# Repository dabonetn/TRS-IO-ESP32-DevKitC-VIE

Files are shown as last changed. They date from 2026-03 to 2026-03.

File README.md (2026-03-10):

# TRS-IO

WORK IN PROGRESS

DO NOT USE YET!

TRS-IO gives a TRS-80 Model 1/III online capabilities and provides
access to a variety of services. TRS-IO currently features the
following capabilities:

1. Access to the <a href="https://retrostore.org">RetroStore</a>
2. <a href="http://frehd.com">FreHD</a> emulation
3. Access to files mounted on a SMB share or located on a micro-SD card
4. Access to remote servers via TCP
5. Virtual printer support

The TRS-IO versions for the Model 1 and Model III have some additional features that
are explained below. The following sections give an overview of TRS-IO as well as setup
instructions. This Github repository contains the complete source code
as well as the KiCad schematics for the PCB (Printed Circuit Board).
For the following descriptions it is assumed that an assembled TRS-IO
card is available.

### Overview

The figure below depicts the overall architecture. The TRS-80 machine
is connected to TRS-IO via the I/O bus.  TRS-IO has a WiFi module that
connects to the local WiFi router. This allows TRS-IO to connect to
the Internet and access various services. Note that TRS-IO can only
connect to a 2.4 GHz WiFi network. It is recommended to use an IPEX
antenna to improve WiFi reception.



### Prerequisites

TRS-IO requires a TRS-80 Model III with 48kB of RAM or a Model 1 with 16kB of RAM.
Floppy disk drives or a cassette tape are not required.

### Power Supply

There are two versions of TRS-IO that are tailored to the Model 1 and Model III. Each version makes use of an ESP32 microcontroller
as well as a Tang Nano 9K FPGA. Both the ESP32 microcontroller as well as the Nano 9K need to be powered. There are two ways of doing
this.

* Power each module independently via two USB cables that connect to the ESP32's micro-USB and the Nano 9K's USB-C connector.
  For this option, the "VU" jumper (mentioned below), <b>SHOULD NOT BE USED</b>.
* Power the ESP32 via the Nano 9K or vice versa. For this option, only one of the modules need to be provided with power. This option
  requires the "VU" jumper.
  
In the following, each variant of TRS-IO is explained in detail.

### TRS-IO for the Model III

The following figure shows the top view of the TRS-IO card for the Model III:



1. 50-pin I/O bus connector
2. High resolution graphics connector
3. 3.5mm audio jack
4. VU jumper
5. HDMI connector
6. Micro-SD card reader
7. Multi-color status LED
8. Micro-USB and USB-C connector
9. Status button

The TRS-IO card needs to be connected to the TRS-80 Model III's I/O
bus via a 50-pin ribbon cable (1). Furthermore, the TRS-IO card needs
a separate power supply via a standard 5V USB charger. Please refer
to the previous section regarding the power supply. The status button
(9) and the multi-color status LED (7) will be explained in the
configuration section. The micro-SD card reader is underneath the
Nano 9K module (6). The 3.5mm audio jack (3) can be connected to a standard
speaker for game sound and Orchestra 90 support. If the high resolution
connectors (2) are connected to the TRS-80, the HDMI connector (5) will
generate a video signal.

### TRS-IO for the Model 1

The following figure shows the top view of the TRS-IO card for the Model 1:



1. 40-pin I/O bus connector
2. Micro-SD card reader
3. HDMI connector
4. Micro-USB and USB-C connector
5. Multi-color status LED
6. Status button
7. VU jumper

The TRS-IO version for the Model 1 features a 40-pin connector that can
directly be connected via a ribbon cable to the I/O bus of a Model 1.
This version of TRS-IO offers the following features:

* HDMI signal of the M1's video screen that includes game sound.
* Upper 32kB RAM (emulated by the Nano 9K FPGA) for a total of 48kB of total RAM.
* 25ms heartbeat timer to trigger the realtime clock.
* FreHD auto-boot for an unmodified M1.

The HDMI connector (3) can be used instead of a CRT monitor. TRS-IO for the M1
also emulates the LE18 graphics cards. The color of the HDMI signal can
be set to white (X=0), green (X=1), and amber (X=2) via the following OUT statements:

```OUT 31,0:OUT 31,5:OUT 31,X```

Please refer to an earlier section on how to provide power to TRS-IO.

### Configuring TRS-IO

The core of the TRS-IO card is an ESP32 microcontroller that features
a WiFi module that is used to connect to a WiFi router. After
physically connecting the TRS-IO card to a TRS-80 Model 1/III as
explained in the previous sections, the WiFi module on the ESP32
microcontroller first needs to be be configured with the credentials
of the local WiFi network.

While in setup mode, the TRS-IO's status LED will continuously blink
in white to indicate that it has not yet been configured. While in
that mode, TRS-IO will create an open access point called
"TRS-IO". Use a laptop to connect to this WiFi network and then use a
browser to visit URL <a
href="http://trs-io.local">trs-io.local</a>. The following web page
should appear in the browser:

<img src="doc/trs-io-web-ui.png" width="50%" />

Some hosts do not correctly handle mDNS that is used to resolve <a
href="http://trs-io.local">trs-io.local</a>. In that case, visit the
IP address <a href="http://192.168.4.1">192.168.4.1</a> instead.
The web interface shown above can be used to configure SSID and password of the WiFi
network that TRS-IO should connect to, the local timezone as well as
the credentials of a SMB share. For open networks leave the WiFi
password field empty. Note that TRS-IO cannot connect to WiFi networks
that use a capture portal. The timezone as well as the SMB share are
not required but will result in limited functionality.

Once all the information is provided, click on submit to upload the
parameters. TRS-IO will automatically reboot and try to connect to the
specified WiFi network. If successful, the LED will turn green for a
few seconds. If the credentials are wrong or if the specified WiFi
network is not accessible, the LED light will turn permanently red.

Note that TRS-IO will store all parameters in its local flash memory,
so the setup only needs to be performed once. Once TRS-IO is connected
to a WiFi router, it should still be possible to access URL <a
href="http://trs-io.local">trs-io.local</a> from a browser on the same
WiFi network. If mDNS is not supported by the host, the following BASIC
program can be used to determine TRS-IO's local IP address that was
assigned by the router:

```
10 OUT 236,16
20 OUT31,0:OUT31,4
30 C=INP(31):IF C=0 THEN END
40 PRINT CHR$(C);
50 GOTO 30
```

The web interface will also display two icons to indicate the status
of the SMB share and the micro-SD card (see screenshot above). Green
icons indicate that TRS-IO has access. Red icons indicate an error.
In that case, hovering the mouse over the red icon will display the
error message. It should be noted that TRS-IO needs to be rebooted
whenever a micro-SD card is inserted or ejected.

Pushing the status button will make the LED flash twice. The first time for
the WiFi status (green: WiFi connected; red: WiFi not connected) and a
second time for the SMB status (green: connected to SMB share; red:
not connected to SMB share). With proper configuration parameters, the
LED should flash green twice. Holding down the push button for more
than three seconds will erase all configuration parameters and place
TRS-IO back into setup mode (status LED flashing white). This
might be necessary if TRS-IO is moved to a different WiFi network.

The status LED indicates the state of TRS-IO:

* Blinking white: TRS-IO is not configured. It will create an open WiFi access point named "TRS-IO"
* Solid green: when TRS-IO has been configured with WiFi credentials and TRS-IO was able
  to connect to the WiFi network, the status LED will light in solid green for several seconds.
* Solid red: TRS-IO was configured with WiFi credentials but it was not possible to connect to the specified
  network. The reason could be wrong credentials or the specified network is itself offline. The push button can be
  used to reset TRS-IO into setup mode in case different credentials need to be provided.
* Solid blue: TRS-IO performs an OTA (Over-the-Air) update. TRS-IO will automatically detect
  newer firmware versions and will download and install the new firmware. The status LED will light solid blue during
  this process.
* Off: the status LED will be off during regular operations when TRS-IO is connected to the specified
  WiFi network and ready to accept commands from the TRS-80 Model III.
 
### FreHD

TRS-IO is compatible with the popular <a
href="http://frehd.com">FreHD</a> hard disk emulator. The FreHD disk
images can either be stored on a SMB share or on a micro-SD card.
If a micro-SD card is inserted, it will take precedence over
a mounted SMB share. Once TRS-IO is configured to access a SMB share,
simply copy the required files such as <a
href="http://members.iinet.net.au/~ianmav/trs80/downloads.htm">FREHD.ROM</a>
to the SMB share. Alternatively, the disk images can be transferred
to the micro-SD card. The IMPORT/EXPORT utilities will access files on the
SMB share or micro-SD card respectively.

### Virtual Printer Interface

TRS-IO support a virtual printer interface. Visiting <a
href="http://trs-io.local/printer">trs-io.local/printer</a> from a browser
will open the printer interface. Any printer output from the M1/MIII will
be displayed in the printer interface. If the host cannot resolve the mDNS name
trs-io.local, the above BASIC program can be used to determine the TRS-80's
IP address.

 ### Launching the native RetroStore Client

The <a href="https://retrostore.org">RetroStore</a> hosts applications
for the Tandy Radio Shack vintage computers and allows to seamlessly
download and run these applications without the need of cassettes or
floppy disks. TRS-IO acts as a gateway to the <a
href="https://retrostore.org">RetroStore</a>. This requires to run a
program on the TRS-80 that interfaces with TRS-IO. This program is
available as a regular <a
href="https://github.com/apuder/TRS-IO/raw/master/src/esp/components/retrostore/rsclient.cmd">CMD</a>
executable.  For TRS-80 machines with attached physical floppy disks,
this CMD executable can be copied to a floppy disk and launched the
usual way. For TRS-80 machines that have neither floppy disk drives
nor cassette drives, it is also possible to bootstrap the native
client via the following short BASIC program:
 
 ```BASIC
 10 OUT236,16
 20 OUT31,3
 30 OUT31,1
 40 N=INP(31)+256*INP(31)
 50 FOR X=1 TO N:POKE20735+X,INP(31):NEXT
 RUN
 SYSTEM
 *? /20736
 ```
 
The above BASIC program will download the CMD executable from TRS-IO
and launch the native client.  Note that this procedure needs to be
repeated every time the TRS-80 is turned on.
 
### Using the native RetroStore Client

After successfully launching the native RetroStore client, the monitor
of the TRS-80 should look like this:
 

 
The screenshot above shows the main menu of the native RetroStore
client. The arrow indicates the currently selected menu item.  The up
and down cursor keys can be used to move between the various menu
items. Hitting the ENTER key will activate the currently selected
menu item. Pressing CLEAR or BREAK in sub-menus will return to the
previous menu.
 
Keyboard controls:
 
 * Cursor up/down: toggle menu selection
 * ENTER: select current menu selection
 * BREAK/CLEAR: exit to previous screen

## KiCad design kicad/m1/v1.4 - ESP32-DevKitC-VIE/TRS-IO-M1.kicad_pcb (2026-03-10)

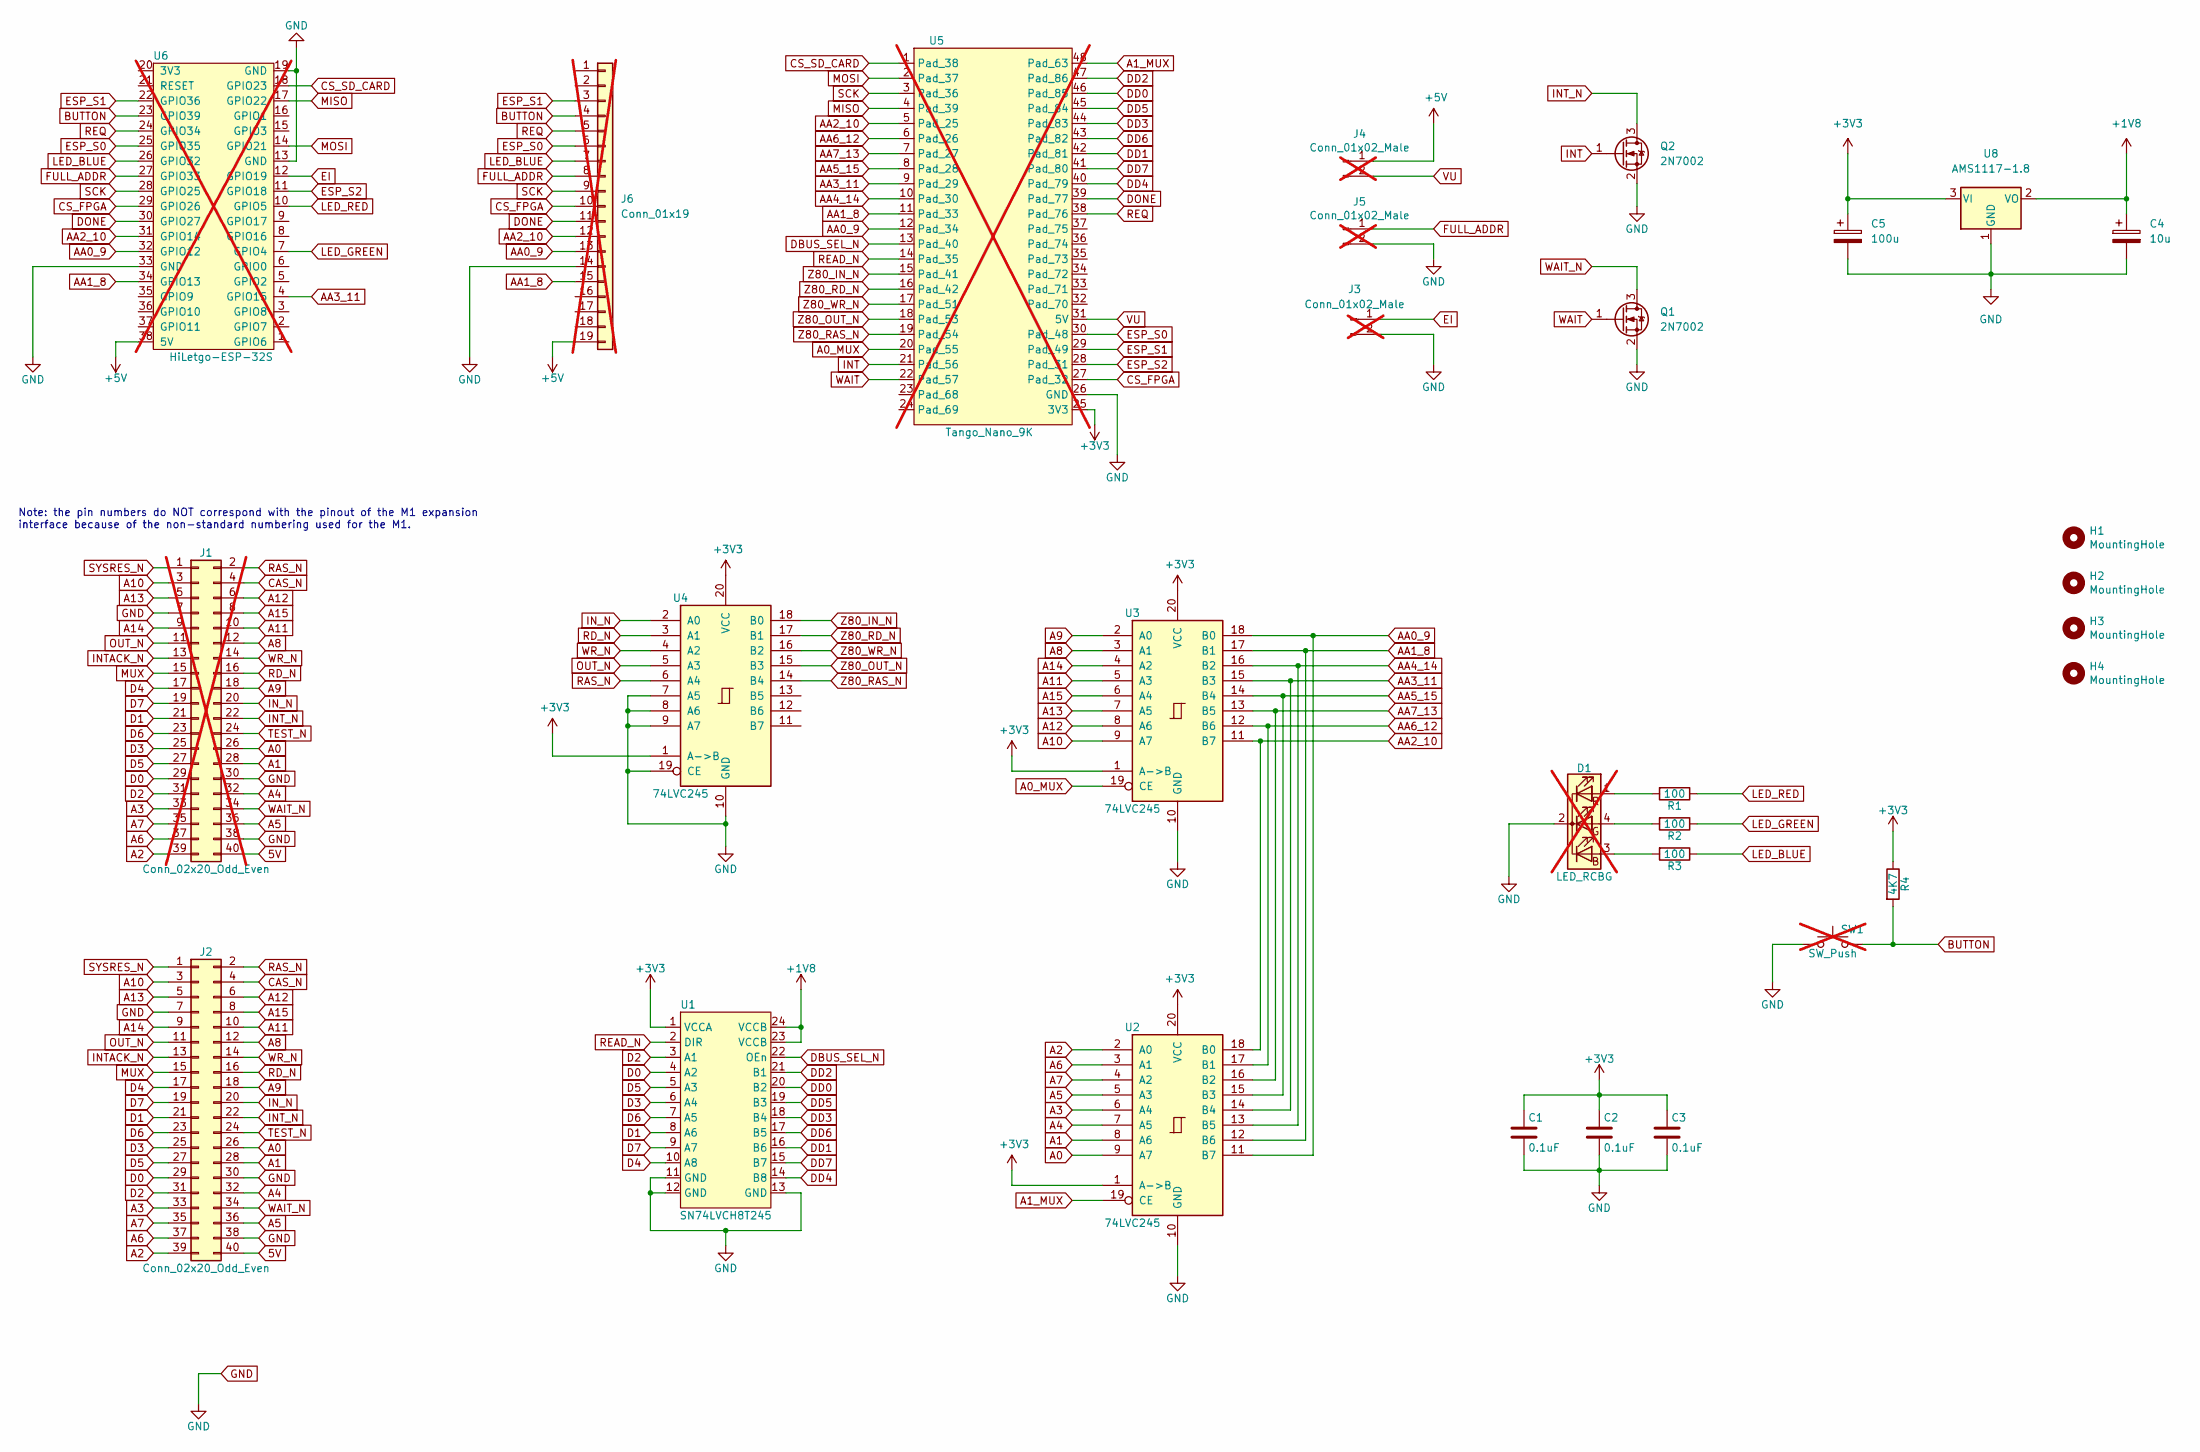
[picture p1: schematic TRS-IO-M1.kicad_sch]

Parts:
C1, C2, C3: 0.1uF; C_0805_2012Metric_Pad1.18x1.45mm_HandSolder
C4: 10u; C_1206_3216Metric_Pad1.33x1.80mm_HandSolder
C5: 100u; C_1206_3216Metric_Pad1.33x1.80mm_HandSolder
D1: LED_RCBG; LED_D5.0mm-4_RGB; not fitted
H1, H2, H3, H4: MountingHole; MountingHole_3mm_Pad_Via
J1: Conn_02x20_Odd_Even; PinHeader_2x20_P2.54mm_Vertical; not fitted
J2: Conn_02x20_Odd_Even; TRSEDGE
J3, J4, J5: Conn_01x02_Male; PinHeader_1x02_P2.54mm_Vertical; not fitted
J6: Conn_01x19; PinHeader_1x19_P2.54mm_Vertical; not fitted
Q1, Q2: 2N7002; SOT-23
R1, R2, R3: 100; R_0805_2012Metric_Pad1.20x1.40mm_HandSolder
R4: 4K7; R_0805_2012Metric_Pad1.20x1.40mm_HandSolder
SW1: SW_Push; SW_PUSH_6mm_H9.5mm; not fitted
U1: SN74LVCH8T245; TSSOP-24_4.4x7.8mm_P0.65mm
U2, U3, U4: 74LVC245; SSOP-20_5.3x7.2mm_P0.65mm_slim
U5: Tango_Nano_9K; DIP-48_W22.9mm; not fitted
U6: HiLetgo-ESP-32S; DIP-38_W22.9mm; not fitted
U8: AMS1117-1.8; SOT-223-3_TabPin2

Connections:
5V: J1.40, J2.40
+1V8: C4.1, U1.23 (VCCB), U1.24 (VCCB), U8.2 (VO)
+3V3: C1.1, C2.1, C3.1, C5.1, R4.1, U1.1 (VCCA), U2.1 (A->B), U2.20 (VCC), U3.1 (A->B), U3.20 (VCC), U4.1 (A->B), U4.20 (VCC), U5.25 (3V3), U8.3 (VI)
+5V: J4.1, J6.19, U6.38 (5V)
A0: J1.26, J2.26, U2.9 (A7)
A0_MUX: U3.19 (CE), U5.20 (Pad_55)
A1: J1.28, J2.28, U2.8 (A6)
A1_MUX: U2.19 (CE), U5.48 (Pad_63)
A2: J1.39, J2.39, U2.2 (A0)
A3: J1.33, J2.33, U2.6 (A4)
A4: J1.32, J2.32, U2.7 (A5)
A5: J1.36, J2.36, U2.5 (A3)
A6: J1.37, J2.37, U2.3 (A1)
A7: J1.35, J2.35, U2.4 (A2)
A8: J1.12, J2.12, U3.3 (A1)
A9: J1.18, J2.18, U3.2 (A0)
A10: J1.3, J2.3, U3.9 (A7)
A11: J1.10, J2.10, U3.5 (A3)
A12: J1.6, J2.6, U3.8 (A6)
A13: J1.5, J2.5, U3.7 (A5)
A14: J1.9, J2.9, U3.4 (A2)
A15: J1.8, J2.8, U3.6 (A4)
AA0_9: J6.13, U2.11 (B7), U3.18 (B0), U5.12 (Pad_34), U6.32 (GPIO12)
AA1_8: J6.15, U2.12 (B6), U3.17 (B1), U5.11 (Pad_33), U6.34 (GPIO13)
AA2_10: J6.12, U2.18 (B0), U3.11 (B7), U5.5 (Pad_25), U6.31 (GPIO14)
AA3_11: U2.14 (B4), U3.15 (B3), U5.9 (Pad_29), U6.4 (GPIO15)
AA4_14: U2.13 (B5), U3.16 (B2), U5.10 (Pad_30)
AA5_15: U2.15 (B3), U3.14 (B4), U5.8 (Pad_28)
AA6_12: U2.17 (B1), U3.12 (B6), U5.6 (Pad_26)
AA7_13: U2.16 (B2), U3.13 (B5), U5.7 (Pad_27)
BUTTON: J6.4, R4.2, SW1.2, U6.23 (GPIO39)
CAS_N: J1.4, J2.4
CS_FPGA: J6.10, U5.27 (Pad_32), U6.29 (GPIO26)
CS_SD_CARD: U5.1 (Pad_38), U6.18 (GPIO23)
D0: J1.29, J2.29, U1.4 (A2)
D1: J1.21, J2.21, U1.8 (A6)
D2: J1.31, J2.31, U1.3 (A1)
D3: J1.25, J2.25, U1.6 (A4)
D4: J1.17, J2.17, U1.10 (A8)
D5: J1.27, J2.27, U1.5 (A3)
D6: J1.23, J2.23, U1.7 (A5)
D7: J1.19, J2.19, U1.9 (A7)
DBUS_SEL_N: U1.22 (OEn), U5.13 (Pad_40)
DD0: U1.20 (B2), U5.46 (Pad_85)
DD1: U1.16 (B6), U5.42 (Pad_81)
DD2: U1.21 (B1), U5.47 (Pad_86)
DD3: U1.18 (B4), U5.44 (Pad_83)
DD4: U1.14 (B8), U5.40 (Pad_79)
DD5: U1.19 (B3), U5.45 (Pad_84)
DD6: U1.17 (B5), U5.43 (Pad_82)
DD7: U1.15 (B7), U5.41 (Pad_80)
DONE: J6.11, U5.39 (Pad_77), U6.30 (GPIO27)
EI: J3.1, U6.12 (GPIO19)
ESP_S0: J6.6, U5.30 (Pad_48), U6.25 (GPIO35)
ESP_S1: J6.3, U5.29 (Pad_49), U6.22 (GPIO36)
ESP_S2: U5.28 (Pad_31), U6.11 (GPIO18)
FULL_ADDR: J5.1, J6.8, U6.27 (GPIO33)
GND: C1.2, C2.2, C3.2, C4.2, C5.2, D1.2 (K), J1.7, J1.30, J1.38, J2.7, J2.30, J2.38, J3.2, J5.2, J6.14, Q1.2 (S), Q2.2 (S), SW1.1, U1.11 (GND), U1.12 (GND), U1.13 (GND), U2.10 (GND), U3.10 (GND), U4.7 (A5), U4.8 (A6), U4.9 (A7), U4.10 (GND), U4.19 (CE), U5.26 (GND), U6.13 (GND), U6.19 (GND), U6.33 (GND), U8.1 (GND)
INT: Q2.1 (G), U5.21 (Pad_56)
INTACK_N: J1.13, J2.13
INT_N: J1.22, J2.22, Q2.3 (D)
IN_N: J1.20, J2.20, U4.2 (A0)
LED_BLUE: J6.7, R3.1, U6.26 (GPIO32)
LED_GREEN: R2.1, U6.7 (GPIO4)
LED_RED: R1.1, U6.10 (GPIO5)
MISO: U5.4 (Pad_39), U6.17 (GPIO22)
MOSI: U5.2 (Pad_37), U6.14 (GPIO21)
MUX: J1.15, J2.15
unnamed: D1.3 (BA), R3.2
unnamed: D1.4 (GA), R2.2
unnamed: D1.1 (RA), R1.2
OUT_N: J1.11, J2.11, U4.5 (A3)
RAS_N: J1.2, J2.2, U4.6 (A4)
RD_N: J1.16, J2.16, U4.3 (A1)
READ_N: U1.2 (DIR), U5.14 (Pad_35)
REQ: J6.5, U5.38 (Pad_76), U6.24 (GPIO34)
SCK: J6.9, U5.3 (Pad_36), U6.28 (GPIO25)
SYSRES_N: J1.1, J2.1
TEST_N: J1.24, J2.24
VU: J4.2, U5.31 (5V)
WAIT: Q1.1 (G), U5.22 (Pad_57)
WAIT_N: J1.34, J2.34, Q1.3 (D)
WR_N: J1.14, J2.14, U4.4 (A2)
Z80_IN_N: U4.18 (B0), U5.15 (Pad_41)
Z80_OUT_N: U4.15 (B3), U5.18 (Pad_53)
Z80_RAS_N: U4.14 (B4), U5.19 (Pad_54)
Z80_RD_N: U4.17 (B1), U5.16 (Pad_42)
Z80_WR_N: U4.16 (B2), U5.17 (Pad_51)

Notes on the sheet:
Note: the pin numbers do NOT correspond with the pinout of the M1 expansion interface because of the non-standard numbering used for the M1.

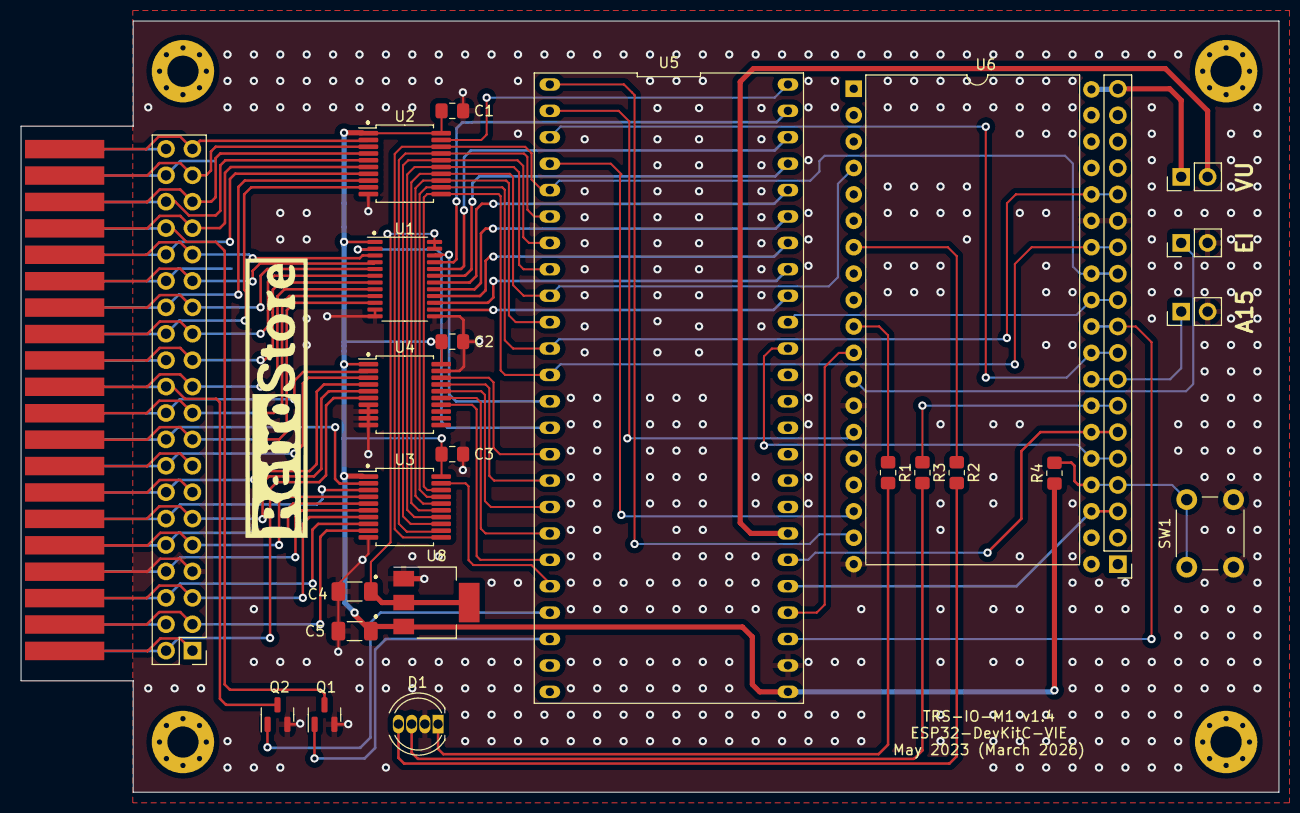
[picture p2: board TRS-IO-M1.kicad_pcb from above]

Board: 2 copper layers, 121.0 x 74.2 mm, 31 parts (0 on the bottom side), 88 nets.

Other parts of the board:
G1: LOGO

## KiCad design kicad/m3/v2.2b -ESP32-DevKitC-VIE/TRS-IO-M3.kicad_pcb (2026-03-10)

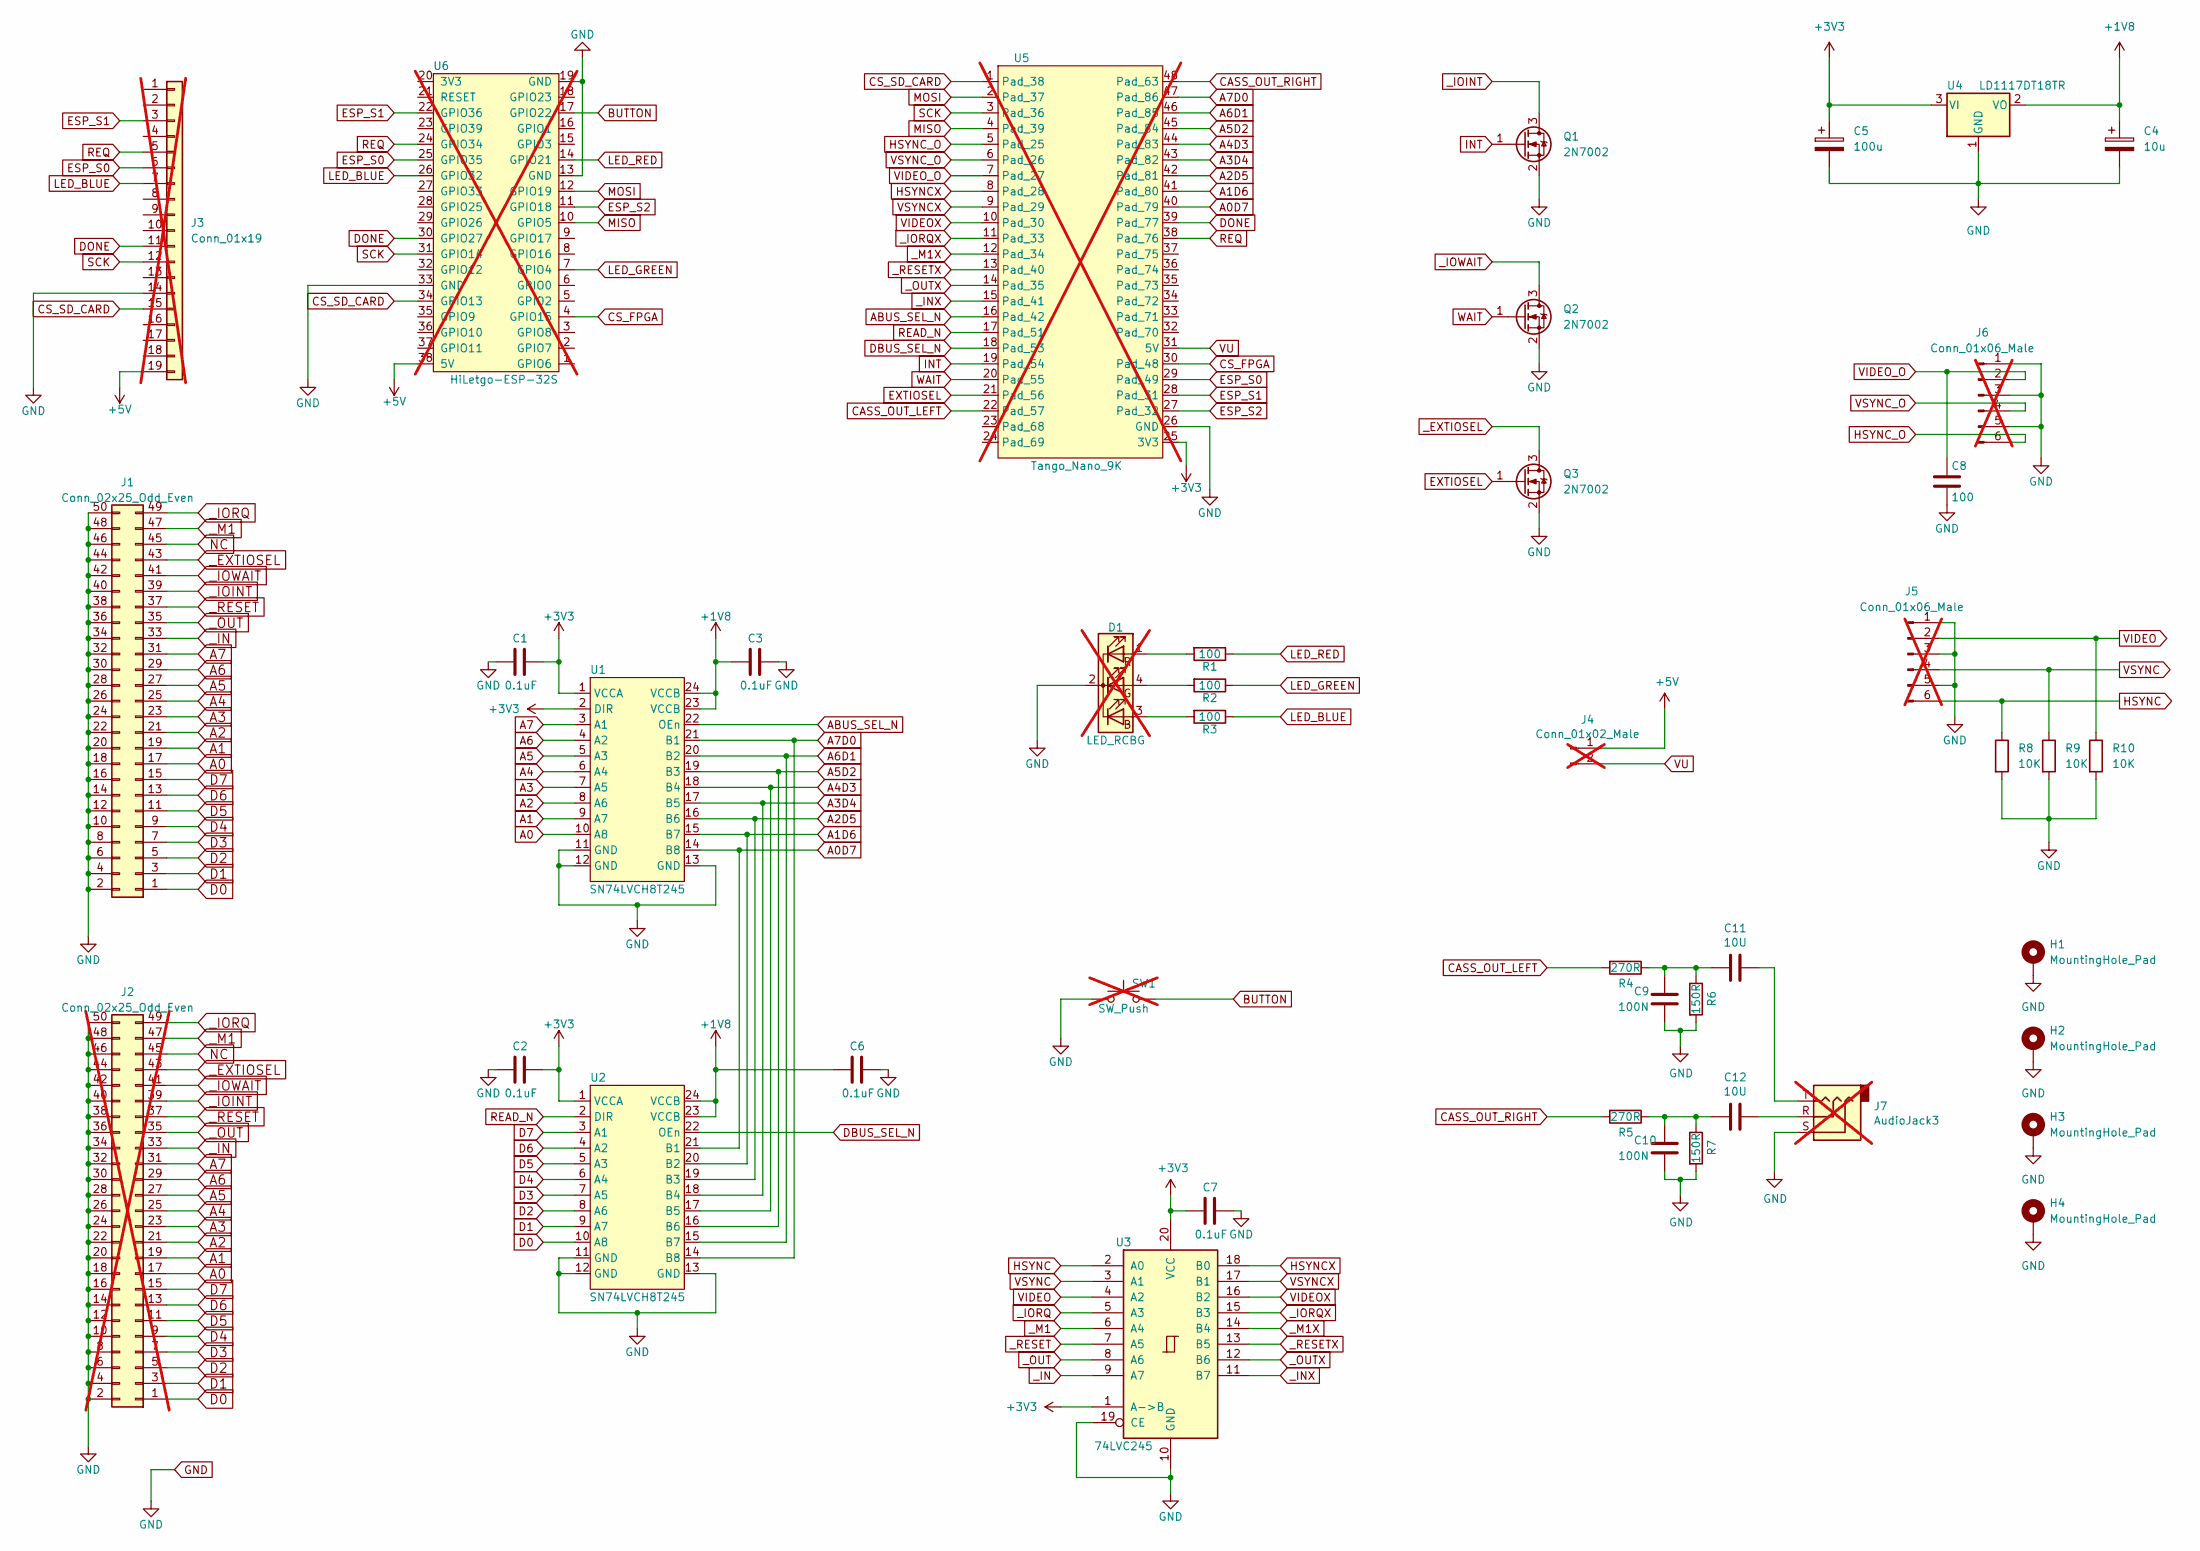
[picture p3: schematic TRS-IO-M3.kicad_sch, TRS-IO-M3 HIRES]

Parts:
C1, C2, C3, C6, C7: 0.1uF; C_0805_2012Metric_Pad1.18x1.45mm_HandSolder
C4: 10u; C_1206_3216Metric_Pad1.33x1.80mm_HandSolder
C5: 100u; C_1206_3216Metric_Pad1.33x1.80mm_HandSolder
C8: 100; C_0805_2012Metric_Pad1.18x1.45mm_HandSolder
C9, C10: 100N; C_0805_2012Metric_Pad1.18x1.45mm_HandSolder
C11, C12: 10U; C_1206_3216Metric_Pad1.33x1.80mm_HandSolder
D1: LED_RCBG; LED_D5.0mm-4_RGB; not fitted
H1, H2, H3, H4: MountingHole_Pad; MountingHole_3mm_Pad_Via
J1: Conn_02x25_Odd_Even; EDGE50
J2: Conn_02x25_Odd_Even; Pin_Header_Straight_2x25_Pitch2.54mm; not fitted
J3: Conn_01x19; PinHeader_1x19_P2.54mm_Vertical; not fitted
J4: Conn_01x02_Male; PinHeader_1x02_P2.54mm_Vertical; not fitted
J5, J6: Conn_01x06_Male; PinHeader_1x06_P2.54mm_Horizontal; not fitted
J7: AudioJack3; Jack_3.5mm_CUI_SJ1-3535NG_Horizontal_CircularHoles; not fitted
Q1, Q2, Q3: 2N7002; SOT-23
R1, R2, R3: 100; R_0805_2012Metric_Pad1.20x1.40mm_HandSolder
R4, R5: 270R; R_0805_2012Metric_Pad1.20x1.40mm_HandSolder
R6, R7: 150R; R_0805_2012Metric_Pad1.20x1.40mm_HandSolder
R8, R9, R10: 10K; R_0805_2012Metric_Pad1.20x1.40mm_HandSolder
SW1: SW_Push; SW_PUSH_6mm_H9.5mm; not fitted
U1, U2: SN74LVCH8T245; TSSOP-24_4.4x7.8mm_P0.65mm
U3: 74LVC245; SSOP-20_5.3x7.2mm_P0.65mm_slim
U4: LD1117DT18TR; TO-252-3_TabPin2
U5: Tango_Nano_9K; DIP-48_W22.9mm; not fitted
U6: HiLetgo-ESP-32S; DIP-38_W22.9mm; not fitted

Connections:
+1V8: C3.2, C4.1, C6.2, U1.23 (VCCB), U1.24 (VCCB), U2.23 (VCCB), U2.24 (VCCB), U4.2 (VO)
+3V3: C1.1, C2.1, C5.1, C7.2, U1.1 (VCCA), U1.2 (DIR), U2.1 (VCCA), U3.1 (A->B), U3.20 (VCC), U4.3 (VI), U5.25 (3V3)
+5V: J3.19, J4.1, U6.38 (5V)
A0: J1.17, J2.17, U1.10 (A8)
A0D7: U1.14 (B8), U2.21 (B1), U5.40 (Pad_79)
A1: J1.19, J2.19, U1.9 (A7)
A1D6: U1.15 (B7), U2.20 (B2), U5.41 (Pad_80)
A2: J1.21, J2.21, U1.8 (A6)
A2D5: U1.16 (B6), U2.19 (B3), U5.42 (Pad_81)
A3: J1.23, J2.23, U1.7 (A5)
A3D4: U1.17 (B5), U2.18 (B4), U5.43 (Pad_82)
A4: J1.25, J2.25, U1.6 (A4)
A4D3: U1.18 (B4), U2.17 (B5), U5.44 (Pad_83)
A5: J1.27, J2.27, U1.5 (A3)
A5D2: U1.19 (B3), U2.16 (B6), U5.45 (Pad_84)
A6: J1.29, J2.29, U1.4 (A2)
A6D1: U1.20 (B2), U2.15 (B7), U5.46 (Pad_85)
A7: J1.31, J2.31, U1.3 (A1)
A7D0: U1.21 (B1), U2.14 (B8), U5.47 (Pad_86)
ABUS_SEL_N: U1.22 (OEn), U5.16 (Pad_42)
BUTTON: SW1.2, U6.17 (GPIO22)
CASS_OUT_LEFT: R4.2, U5.22 (Pad_57)
CASS_OUT_RIGHT: R5.2, U5.48 (Pad_63)
CS_FPGA: U5.30 (Pad_48), U6.4 (GPIO15)
CS_SD_CARD: J3.15, U5.1 (Pad_38), U6.34 (GPIO13)
D0: J1.1, J2.1, U2.10 (A8)
D1: J1.3, J2.3, U2.9 (A7)
D2: J1.5, J2.5, U2.8 (A6)
D3: J1.7, J2.7, U2.7 (A5)
D4: J1.9, J2.9, U2.6 (A4)
D5: J1.11, J2.11, U2.5 (A3)
D6: J1.13, J2.13, U2.4 (A2)
D7: J1.15, J2.15, U2.3 (A1)
DBUS_SEL_N: U2.22 (OEn), U5.18 (Pad_53)
DONE: J3.11, U5.39 (Pad_77), U6.30 (GPIO27)
ESP_S0: J3.6, U5.29 (Pad_49), U6.25 (GPIO35)
ESP_S1: J3.3, U5.28 (Pad_31), U6.22 (GPIO36)
ESP_S2: U5.27 (Pad_32), U6.11 (GPIO18)
EXTIOSEL: Q3.1 (G), U5.21 (Pad_56)
GND: C1.2, C2.2, C3.1, C4.2, C5.2, C6.1, C7.1, C8.2, C9.2, C10.2, D1.2 (K), H1.1, H2.1, H3.1, H4.1, J1.2, J1.4, J1.6, J1.8, J1.10, J1.12, J1.14, J1.16, J1.18, J1.20, J1.22, J1.24, J1.26, J1.28, J1.30, J1.32, J1.34, J1.36, J1.38, J1.40, J1.42, J1.44, J1.46, J1.48, J1.50, J2.2, J2.4, J2.6, J2.8, J2.10, J2.12, J2.14, J2.16, J2.18, J2.20, J2.22, J2.24, J2.26, J2.28, J2.30, J2.32, J2.34, J2.36, J2.38, J2.40, J2.42, J2.44, J2.46, J2.48, J2.50, J3.14, J5.1, J5.3, J5.5, J6.1, J6.3, J6.5, J7.S, Q1.2 (S), Q2.2 (S), Q3.2 (S), R6.2, R7.2, R8.2, R9.2, R10.2, SW1.1, U1.11 (GND), U1.12 (GND), U1.13 (GND), U2.11 (GND), U2.12 (GND), U2.13 (GND), U3.10 (GND), U3.19 (CE), U4.1 (GND), U5.26 (GND), U6.13 (GND), U6.19 (GND), U6.33 (GND)
HSYNC: J5.6, R8.1, U3.2 (A0)
HSYNCX: U3.18 (B0), U5.8 (Pad_28)
HSYNC_O: J6.6, U5.5 (Pad_25)
INT: Q1.1 (G), U5.19 (Pad_54)
LED_BLUE: J3.7, R3.1, U6.26 (GPIO32)
LED_GREEN: R2.1, U6.7 (GPIO4)
LED_RED: R1.1, U6.14 (GPIO21)
MISO: U5.4 (Pad_39), U6.10 (GPIO5)
MOSI: U5.2 (Pad_37), U6.12 (GPIO19)
NC: J1.45, J2.45
unnamed: C10.1, C12.2, R5.1, R7.1
unnamed: C11.1, J7.T
unnamed: C9.1, C11.2, R4.1, R6.1
unnamed: C12.1, J7.R
unnamed: D1.3 (BA), R3.2
unnamed: D1.4 (GA), R2.2
unnamed: D1.1 (RA), R1.2
READ_N: U2.2 (DIR), U5.17 (Pad_51)
REQ: J3.5, U5.38 (Pad_76), U6.24 (GPIO34)
SCK: J3.12, U5.3 (Pad_36), U6.31 (GPIO14)
VIDEO: J5.2, R10.1, U3.4 (A2)
VIDEOX: U3.16 (B2), U5.10 (Pad_30)
VIDEO_O: C8.1, J6.2, U5.7 (Pad_27)
VSYNC: J5.4, R9.1, U3.3 (A1)
VSYNCX: U3.17 (B1), U5.9 (Pad_29)
VSYNC_O: J6.4, U5.6 (Pad_26)
VU: J4.2, U5.31 (5V)
WAIT: Q2.1 (G), U5.20 (Pad_55)
_EXTIOSEL: J1.43, J2.43, Q3.3 (D)
_IN: J1.33, J2.33, U3.9 (A7)
_INX: U3.11 (B7), U5.15 (Pad_41)
_IOINT: J1.39, J2.39, Q1.3 (D)
_IORQ: J1.49, J2.49, U3.5 (A3)
_IORQX: U3.15 (B3), U5.11 (Pad_33)
_IOWAIT: J1.41, J2.41, Q2.3 (D)
_M1: J1.47, J2.47, U3.6 (A4)
_M1X: U3.14 (B4), U5.12 (Pad_34)
_OUT: J1.35, J2.35, U3.8 (A6)
_OUTX: U3.12 (B6), U5.14 (Pad_35)
_RESET: J1.37, J2.37, U3.7 (A5)
_RESETX: U3.13 (B5), U5.13 (Pad_40)

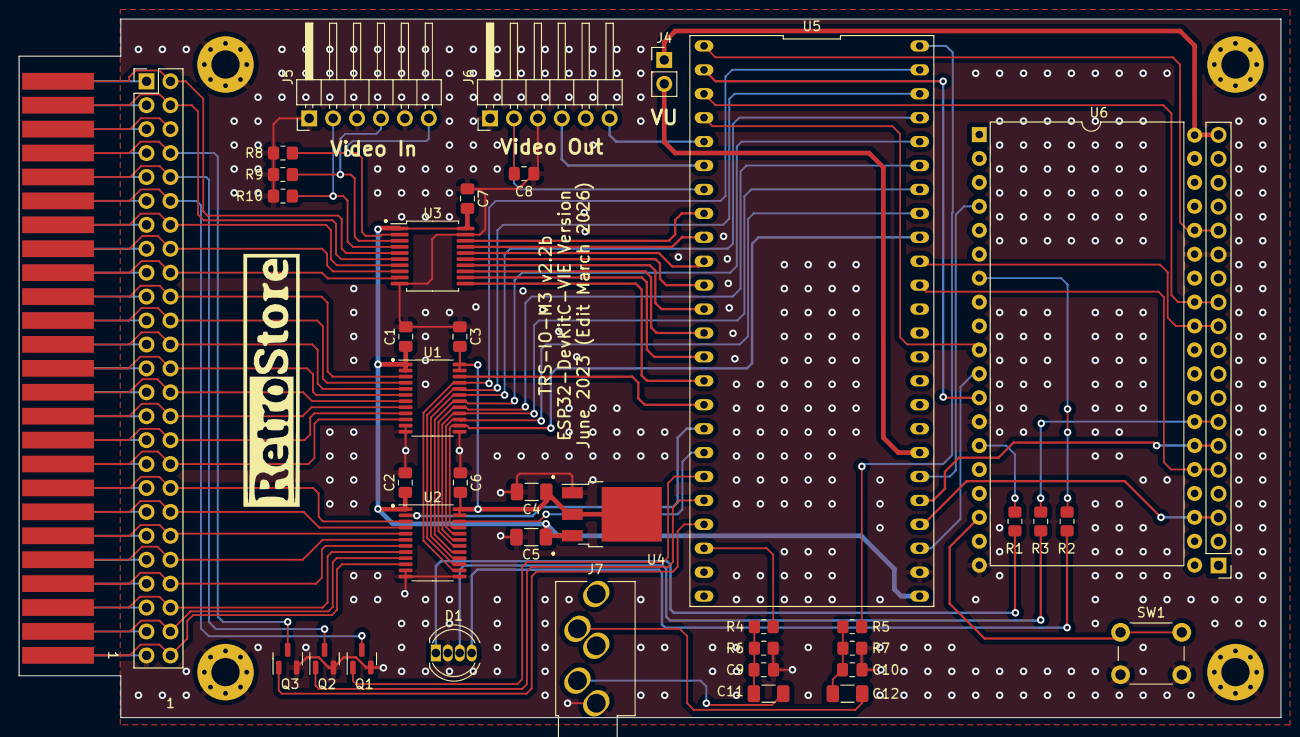
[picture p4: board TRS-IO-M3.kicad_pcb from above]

Board: 2 copper layers, 134.0 x 74.2 mm, 45 parts (0 on the bottom side), 81 nets.

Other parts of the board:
G1: LOGO

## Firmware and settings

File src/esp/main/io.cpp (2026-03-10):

#include "trs-io.h"
#include "frehd.h"
#include "io.h"
#include "button.h"
#include "led.h"
#include "settings.h"
#include "spi.h"
#include "wifi.h"
#include "http.h"
#include "ptrs.h"
#include "event.h"
#include "trs-fs.h"
#include "esp_task.h"
#include "esp_event.h"
#include "tcpip.h"
#include "retrostore.h"
#include "retrostore-defs.h"
#include <string.h>
#include "esp_system.h"
#include "esp_log.h"
#include "driver/gpio.h"
#include "freertos/event_groups.h"
#include "freertos/timers.h"
#include "web_debugger.h"
#include "keyb.h"
#include "jtag.h"
#include "spi.h"
#include "rst.h"

#define ESP_REQ GPIO_NUM_34
#ifdef CONFIG_TRS_IO_PP
#define ESP_DONE GPIO_NUM_18
#define SD_CARD GPIO_NUM_4
#else
#define ESP_DONE GPIO_NUM_27
#define ESP_FULL_ADDR GPIO_NUM_33
#endif


#define ADJUST(x) ((x) < 32 ? (x) : (x) - 32)

#define MASK_ESP_REQ (1 << ADJUST(ESP_REQ))
#define MASK64_ESP_REQ (1ULL << ESP_REQ)
#define MASK_ESP_DONE (1 << ADJUST(ESP_DONE))
#define MASK64_ESP_DONE (1ULL << ESP_DONE)
#ifndef CONFIG_TRS_IO_PP
#define MASK_ESP_FULL_ADDR (1 << ADJUST(ESP_FULL_ADDR))
#define MASK64_ESP_FULL_ADDR (1ULL << ESP_FULL_ADDR)
#endif


static volatile bool DRAM_ATTR trigger_trs_io_action = false;


#define IO_CORE1_ENABLE_INTR BIT0
#define IO_CORE1_DISABLE_INTR BIT1
#define TRS_IO_DONE BIT2

static volatile bool io_task_started = false;
static volatile uint8_t DRAM_ATTR intr_event = 0;


#ifdef ENABLE_XRAY
/***********************************************************************************
 * XRay
 ***********************************************************************************/

#include "retrostore.h"

extern retrostore::RsSystemState trs_state;
extern int trs_state_token;

#define XRAY_PC_OFFSET 11

extern const uint8_t xray_stub_start[] asm("_binary_xray_stub_bin_start");
extern const uint8_t xray_stub_end[] asm("_binary_xray_stub_bin_end");
static const uint8_t xray_stub_len = xray_stub_end - xray_stub_start;


static union {
  XRAY_Z80_REGS xray_z80_regs;
  uint8_t vram[sizeof(XRAY_Z80_REGS)];
} xray_vram_alt;


#define XRAY_STATUS_RUN 0
#define XRAY_STATUS_CONTINUE 1
#define XRAY_STATUS_BREAKPOINT 2

static volatile uint8_t xray_status = XRAY_STATUS_RUN;
static volatile bool trigger_xray_action = false;

#define XRAY_MAX_BREAKPOINTS 5

static void setup_xram_stub() {
  while(spi_get_cookie() != FPGA_COOKIE) {
    vTaskDelay(10);
  }
  for (int i = 0; i < xray_stub_len; i++) {
    spi_xram_poke_code(i, xray_stub_start[i]);
  }
  spi_xram_poke_data(0, 0xc9); // 0xc9 == Z80 RET
}

static char* on_trx_get_resource(TRX_RESOURCE_TYPE type) {
  return NULL;
}

void on_trx_control_callback(TRX_CONTROL_TYPE type) {
  if (type == TRX_CONTROL_TYPE_STEP ||
      type == TRX_CONTROL_TYPE_CONTINUE) {
    spi_xray_resume();
    xray_status = XRAY_STATUS_RUN;
  }
}

void on_trx_get_state_update(TRX_SystemState* state) {
  printf("on_trx_get_state_update\n");
  state->paused = xray_status != XRAY_STATUS_RUN;
  if (state->paused) {
    printf("Hit breakpoint\n");
  }
    for (int i = 0; i < sizeof(XRAY_Z80_REGS); i++) {
      xray_vram_alt.vram[sizeof(XRAY_Z80_REGS) - 1 - i] = spi_xram_peek_data(255 - i);
    }

    state->registers.pc = xray_vram_alt.xray_z80_regs.pc - XRAY_PC_OFFSET;
    state->registers.sp = xray_vram_alt.xray_z80_regs.sp;
    state->registers.af = xray_vram_alt.xray_z80_regs.af;
    state->registers.bc = xray_vram_alt.xray_z80_regs.bc;
    state->registers.de = xray_vram_alt.xray_z80_regs.de;
    state->registers.hl = xray_vram_alt.xray_z80_regs.hl;

    state->registers.af_prime = xray_vram_alt.xray_z80_regs.af_p;
    state->registers.bc_prime = xray_vram_alt.xray_z80_regs.bc_p;
    state->registers.de_prime = xray_vram_alt.xray_z80_regs.de_p;
    state->registers.hl_prime = xray_vram_alt.xray_z80_regs.hl_p;
    state->registers.ix = xray_vram_alt.xray_z80_regs.ix;
    state->registers.iy = xray_vram_alt.xray_z80_regs.iy;

    // Not supported.
    state->registers.i = 0;
    state->registers.iff1 = 0;
    state->registers.iff2 = 0;
  //}
}

void on_trx_add_breakpoint(int bp_id, uint16_t addr, TRX_BREAK_TYPE type) {
  if (type != TRX_BREAK_PC) return;
  spi_set_breakpoint(bp_id, addr);
  printf("set breakpoint(%d): 0x%04x\n", bp_id, addr);
}

void on_trx_remove_breakpoint(int bp_id) {
  spi_clear_breakpoint(bp_id);
  printf("clear breakpoint(%d)\n", bp_id);
}

uint8_t trx_read_memory(uint16_t addr) {
//  return spi_bram_peek(addr);
  uint8_t d = spi_bram_peek(addr);
  printf("peek(%04x): %02x\n", addr, d);
  return d;
}

void trx_write_memory(uint16_t addr, uint8_t value) {
  spi_bram_poke(addr, value);
}

static void init_xray()
{
#ifndef CONFIG_TRS_IO_PP
  bool full_addr = !gpio_get_level(ESP_FULL_ADDR);
#else
  bool full_addr = false;
#endif

  TRX_Context* ctx = get_default_trx_context();
  ctx->system_name = "Model 1";
  ctx->model = MODEL_I;
  ctx->capabilities.memory_range.start = full_addr ? 0 : 0x8000;
  ctx->capabilities.memory_range.length = 20;  // For demo only. fill program covered.
  ctx->capabilities.max_breakpoints = XRAY_MAX_BREAKPOINTS;
  ctx->capabilities.alt_single_step_mode = true;

  // TODO the rest....
  ctx->control_callback = &on_trx_control_callback;
  ctx->read_memory = &trx_read_memory;
  ctx->write_memory = &trx_write_memory;
  ctx->breakpoint_callback = &on_trx_add_breakpoint;
  ctx->remove_breakpoint_callback = &on_trx_remove_breakpoint;
  ctx->get_resource = &on_trx_get_resource;
  ctx->get_state_update = &on_trx_get_state_update;


  spi_set_full_addr(full_addr);
  init_trs_xray(ctx);
  setup_xram_stub();
}
#endif

//-----------------------------------------------------------------

static inline uint8_t dbus_read()
{
  return spi_dbus_read();
}

static inline void dbus_write(uint8_t d)
{
  spi_dbus_write(d);
}

static inline uint8_t abus_read()
{
  return spi_abus_read();
}

static inline void trs_io_read() {
  if (!trigger_trs_io_action) {
    uint8_t data = dbus_read();
    if (!TrsIO::outZ80(data)) {
      trigger_trs_io_action = true;
    }
  }
}

static inline void trs_io_write() {
  uint8_t d = trigger_trs_io_action ? 0xff : TrsIO::inZ80();
  dbus_write(d);
}

static inline void frehd_read(uint8_t port) {
  uint8_t data = dbus_read();
  frehd_out(port, data);
}

static inline void frehd_write(uint8_t port) {
  uint8_t d = frehd_in(port);
  dbus_write(d);
}

static inline void printer_read() {
  uint8_t d = trs_printer_read();
  dbus_write(d);
}

static inline void printer_write() {
  uint8_t data = dbus_read();
  trs_printer_write(data);
}

static volatile bool DRAM_ATTR esp_req_triggered = false;
static volatile uint8_t DRAM_ATTR sd_card_eject_countdown = 0;

static void IRAM_ATTR esp_req_isr_handler(void* arg)
{
  esp_req_triggered = true;
}

#ifdef CONFIG_TRS_IO_PP
static void IRAM_ATTR sd_card_eject_isr_handler(void* arg)
{
  sd_card_eject_countdown = 0xff;
}
#endif
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

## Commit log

2026-03-10 First changes upload
    Changed boards to support GPIOs 35 & 36, no gerbers yet.
    Changed source code for flash size, and gpio pins.
    [TRS-IO-M1-B_Cu.gbr, TRS-IO-M1-B_Mask.gbr, TRS-IO-M1-B_Silkscreen.gbr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]
2026-03-10 added gerbers
    [TRS-IO-M1-B_Cu.gbr, TRS-IO-M1-B_Mask.gbr, TRS-IO-M1-B_Silkscreen.gbr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]
